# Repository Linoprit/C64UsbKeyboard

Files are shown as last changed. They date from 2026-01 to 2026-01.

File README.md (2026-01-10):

# C64UsbKeyboard
### What it does
Connects old Keyboards from Commodore 64 machines to USB, so you can plug them into Retro [C64Nano](https://github.com/MiSTle-Dev/C64Nano) devices. 

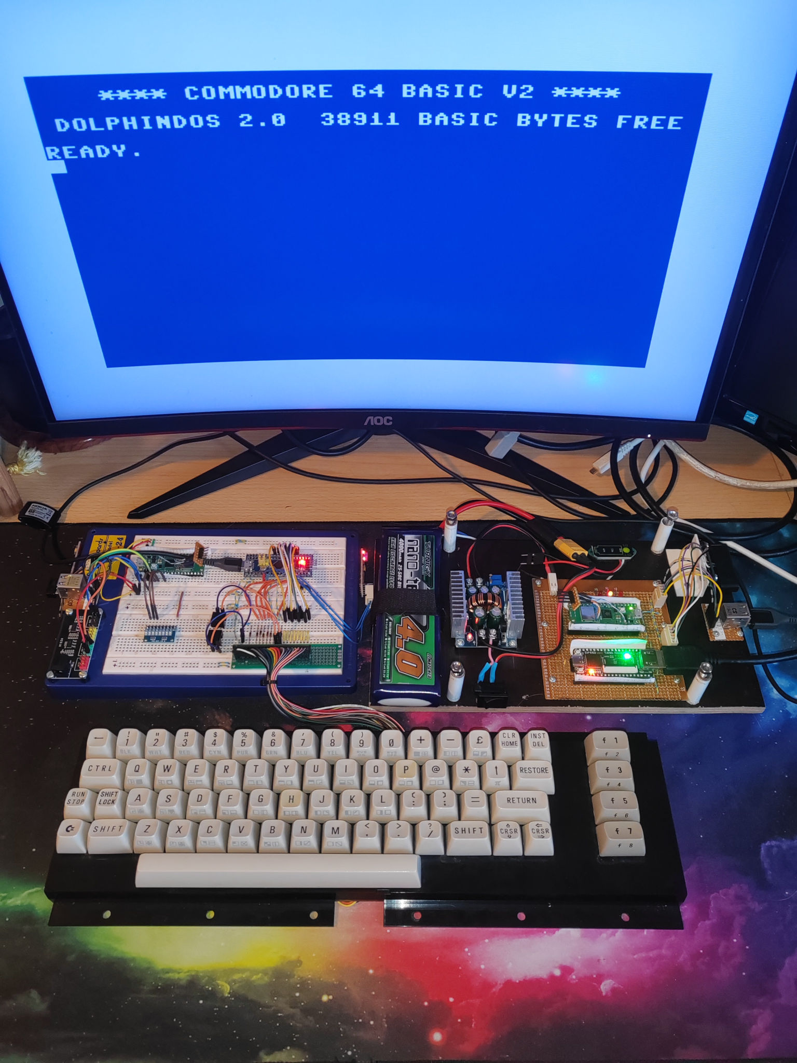
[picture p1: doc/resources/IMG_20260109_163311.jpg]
 

On the left side the breadboard prototype with an aditional RP2040. Right to it my hand soldered C64Nano powered by battery.    

## Why?
Reviving a 40-year-old computer is, well, a questionable idea. But when I heard about Stefan Voss's truly amazing project, I simply had no choice. I had to rebuild it.

Read more about this Retro Computing project here: [C64Nano](https://github.com/MiSTle-Dev/C64Nano?tab=readme-ov-file) and  [MiSTle Develoment](https://github.com/MiSTle-Dev).
Essentially, it's an FPGA and a microcontroller that have been put together to rebuild old computers.

The C64 Nano was working, and I had a great summer playing all the old games I'd played decades ago. But something was missing for a proper retro machine. I remembered buying a broken C64 at a flea market years ago, and that was it! I wanted to take that case and put everything in it. Perfect.

Without question, the original keyboard must work, and that brings us to the point. How do we connect this old keyboard to the C64Nano Companion Board?

To solve this, I thought in many directions, for example extend the Companion Board with a I2C interface, or use the [WeAct RP2350B](https://github.com/WeActStudio/WeActStudio.RP2350BCoreBoard/tree/main) board as Companion, which has plenty of IOs. 

The solution implemented here, simply uses a Bluepill board connected to the USB interface of the C64Nano computer. Easy to build, easy to connect and I have plenty of those boards lying around.

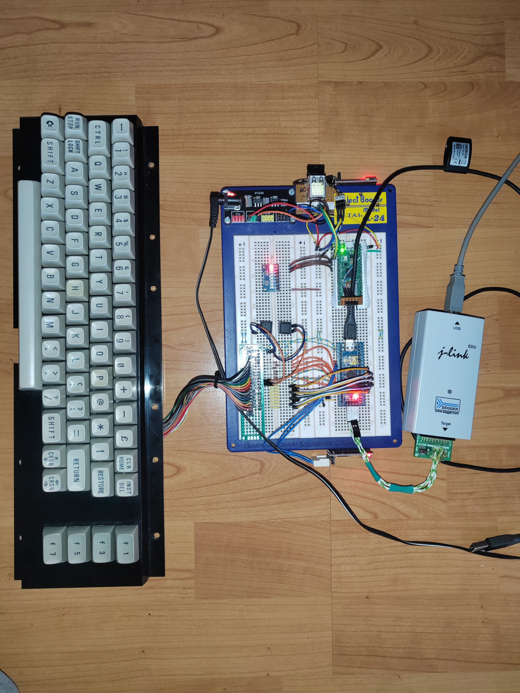
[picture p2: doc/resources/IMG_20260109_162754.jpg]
 

The breadboard with keyboard and programmer. 

After a short search, I found Bob Grant's article in which he described exactly what I wanted to do: [Use a Real Commodore 64 as a USB Keyboard for the VICE emulator](https://bytesnbits.co.uk/commodore-64-usb-keyboard/). He even published his code: [ArduinoKeyboard_C64.ino](https://github.com/getis/c64-usb-keyboard).

Bob uses the Arduino keyboard library, which, however, takes into account the country-specific keyboard layout.
I wanted a mapping of the keyboard matrix to HID codes. This approach is more transparent and easier to debug.

## How to
Well, have a look into the doc folder, there is the schematic. Solder a prototype board, build your own PCB, do what you want :-)

The Bluepill board I used is a Stm32F103C8T6, programmed with a JLink Edu device. 
If you don't want to build the code, simply flash the [release binaries](https://github.com/Linoprit/C64UsbKeyboard/releases). Use a [ST-Link](https://www.google.com/search?q=st+link) device, if you don't own a Segger JLink.

To build the project, you need to install [PlatformIo](https://platformio.org/). The project settings are in platformio.ini.

In the doc folder are some other documents I found usefull. Use them as reference.

## The code
Overall, I used Bob's software and the Arduino Keyboard Library source code.

One small problem arose with the cursor movement of the companion board's OSD. It doesn't accept Shift + Arrow-Up. Therefore, there's a block in the code that intercepts this key combination and sends the correct HID code for Arrow-Up.

Another question was, what to do with the F12 and the play tape keys. Fortunately Bob added the Restore key to the matrix with an addtional row and column. So I simply added two buttons into the matrix and mapped them to corresponding functions.

Oddly enough, I was able to do without key debouncing. If problems arise unexpectedly, it can easily be added later.

> Unplug the Bluepill from USB, before flashing. Otherwise, there is a good chance your host's USB-Driver will get crashed and you need to reboot. The Stm32f103 has no automatic disconnect circuit.

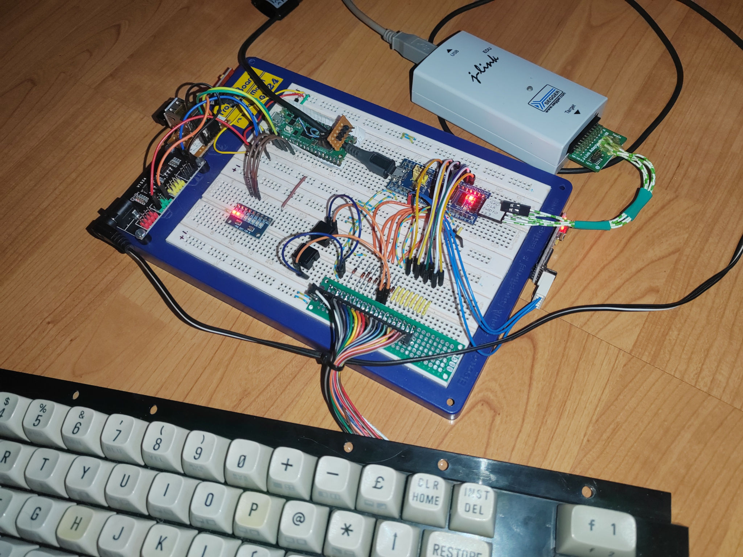
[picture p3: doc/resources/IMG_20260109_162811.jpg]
 

Hope this project is useful to someone.

Have fun.

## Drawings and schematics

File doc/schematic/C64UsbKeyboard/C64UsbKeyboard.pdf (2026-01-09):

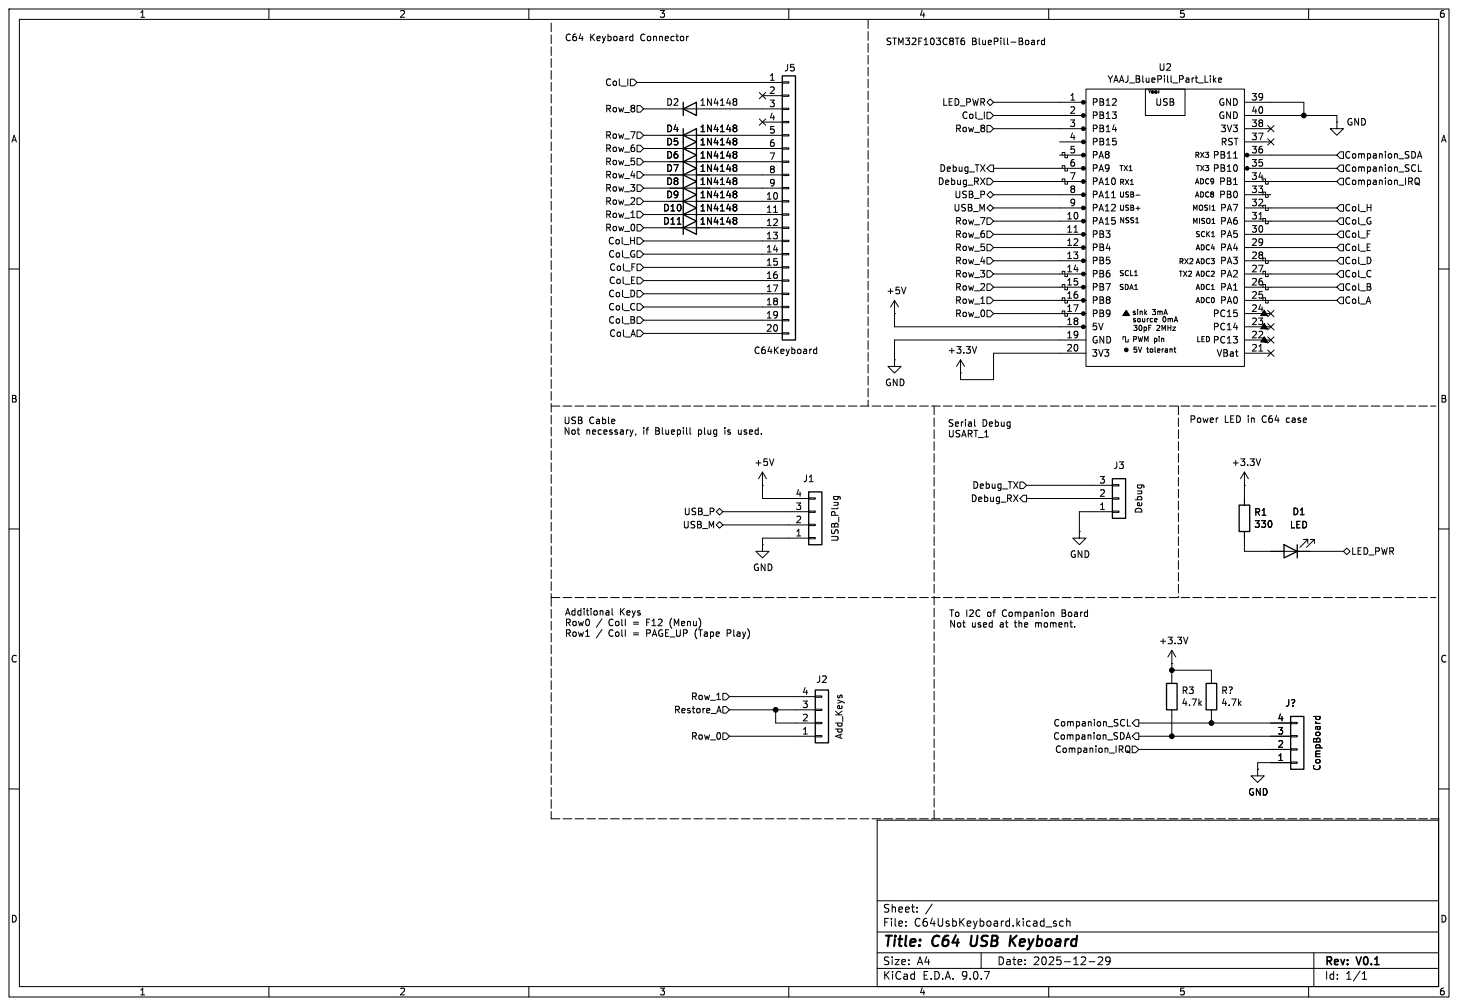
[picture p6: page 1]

Y@@J 30pF 2MHz 5V tolerant source 0mA USB
TX1 RX1 SCL1 SDA1 NSS1 USB- USB+PWM pin

Id: 1/1 Title: C64 USB Keyboard

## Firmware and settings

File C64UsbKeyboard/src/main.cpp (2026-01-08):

// Refer to
// https://bytesnbits.co.uk/commodore-64-usb-keyboard/
// https://github.com/getis/c64-usb-keyboard

#include "MatrixDriver.h"
#include "RawKey.h"
#include "appConfig.h"
#include "stm32f103Config.h"
#include <Arduino.h>
#include "KeysToHid.h"


// ToDo:
// 8 / 8 = Restore = HID KEY_F11
// Missing: Menu = HID KEY_F12
// Missing: TapePlay = HID KEY_PAGEUP
// Modifier Keys (row/col):
// L-Shift (3/1),
// R-Shift (4/6),
// C= (5/0),
//


RowPinsArray rowPins = {row0, row1, row2, row3, row4, row5, row6, row7, row8};
ColPinsArray colPins = {columnA, columnB, columnC, columnD, columnE,
                        columnF, columnG, columnH, columnI};

MatrixDriver matrix = MatrixDriver(rowPins, colPins);
KeysToHid keysToHid;

void setup() {
  Serial.begin(SERIAL_BAUDRATE);
  USB_Begin();
  
  for (uint8_t colPin : colPins) {
    pinMode(colPin, INPUT_PULLUP);
  }

  // init rows as output and set high - inactive
  for (uint8_t rowPin : rowPins) {
    pinMode(rowPin, OUTPUT);
    digitalWrite(rowPin, HIGH);
  }

  Serial.println("finished setup");
  delay(10);
}

void loop() {

  matrix.cycle();

  if (matrix.hasChanged) {
    keysToHid.reportKeys(matrix.actKeys, matrix.scannedKeys);

    for (uint_fast8_t i = 0; i < matrix.scannedKeys; i++) {
      Serial.printf("row: %i / col: %i\n", matrix.actKeys[i].row,
                    matrix.actKeys[i].col);
    }
    if (matrix.scannedKeys == 0) {
      Serial.println("Released");
    }

    keysToHid.dumpKeyReport();
  }

  delay(1);
}

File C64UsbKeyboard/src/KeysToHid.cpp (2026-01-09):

/*
  This is a derivative of Arduinos Keyboard.h, originally by Peter Barrett
*/

#include "C64ToHidKeyMap.h"
#include "KeysToHid.h"
#include <string>

#if defined(_USING_HID)

const uint8_t _hidReportDescriptor[] PROGMEM = {

    //  Keyboard
    0x05, 0x01, // USAGE_PAGE (Generic Desktop)  // 47
    0x09, 0x06, // USAGE (Keyboard)
    0xa1, 0x01, // COLLECTION (Application)
    0x85, 0x02, //   REPORT_ID (2)
    0x05, 0x07, //   USAGE_PAGE (Keyboard)

    0x19, 0xe0, //   USAGE_MINIMUM (Keyboard LeftControl)
    0x29, 0xe7, //   USAGE_MAXIMUM (Keyboard Right GUI)
    0x15, 0x00, //   LOGICAL_MINIMUM (0)
    0x25, 0x01, //   LOGICAL_MAXIMUM (1)
    0x75, 0x01, //   REPORT_SIZE (1)

    0x95, 0x08, //   REPORT_COUNT (8)
    0x81, 0x02, //   INPUT (Data,Var,Abs)
    0x95, 0x01, //   REPORT_COUNT (1)
    0x75, 0x08, //   REPORT_SIZE (8)
    0x81, 0x03, //   INPUT (Cnst,Var,Abs)

    0x95, 0x06, //   REPORT_COUNT (6)
    0x75, 0x08, //   REPORT_SIZE (8)
    0x15, 0x00, //   LOGICAL_MINIMUM (0)
    0x25, 0x73, //   LOGICAL_MAXIMUM (115)
    0x05, 0x07, //   USAGE_PAGE (Keyboard)

    0x19, 0x00, //   USAGE_MINIMUM (Reserved (no event indicated))
    0x29, 0x73, //   USAGE_MAXIMUM (Keyboard Application)
    0x81, 0x00, //   INPUT (Data,Ary,Abs)
    0xc0,       // END_COLLECTION
};

KeysToHid::KeysToHid(void) {
  static HIDSubDescriptor node(_hidReportDescriptor,
                               sizeof(_hidReportDescriptor));
  HID().AppendDescriptor(&node);
}

void KeysToHid::sendReport(KeyReport *keys) {
  HID().SendReport(2, keys, sizeof(KeyReport));
}

void KeysToHid::reportKeys(RawKeysArray rawKeys, uint8_t scannedKeys) {
  HidKeysArray hidKeys;

  releaseAll();

  if (scannedKeys != 0) {
    for (uint_fast8_t i = 0; i < scannedKeys; i++) {
      RawKey rawKey = rawKeys[i];
      hidKeys[i] = rawToHid(rawKey);
    }

    if (shiftAndCursorActive(hidKeys, scannedKeys)) {
      writeCursorToReport(hidKeys, scannedKeys);
    } else {
      writeHidToReport(hidKeys, scannedKeys);
    }
  }

  sendReport(&_keyReport);
}

// Unfortunately the FPGA Companion OSD does not recognize Shift-Cursor keys. 
// So, if we detect Shift and Cursor down or right, we sent the corresponding
// HID-Key and ignore all other keys. 
void KeysToHid::writeCursorToReport(HidKeysArray hidKeys, uint8_t scannedKeys) {
  uint_fast8_t keySlot = 0;
  for (uint_fast8_t i = 0; i < scannedKeys; i++) {
    uint8_t hidCode = hidKeys[i];

    if (hidCode == KEY_RIGHT) {
      _keyReport.keys[keySlot++] = KEY_LEFT; 
    }
    if (hidCode == KEY_DOWN) {
      _keyReport.keys[keySlot++] = KEY_UP; 
    }
    if (keySlot > 5) { 
      break;
    }
  }
}

bool KeysToHid::shiftAndCursorActive(HidKeysArray hidKeys,
                                     uint8_t scannedKeys) {
  bool shiftFlag = false;
  bool cursorFlag = false;

  for (uint_fast8_t i = 0; i < scannedKeys; i++) {
    uint8_t hidCode = hidKeys[i];
    if ((hidCode == KEY_RIGHTSHIFT) || (hidCode == KEY_LEFTSHIFT)) {
      shiftFlag = true;
    }
    if ((hidCode == KEY_RIGHT) || (hidCode == KEY_DOWN)) {
      cursorFlag = true;
    }
    if (shiftFlag && cursorFlag) {
      return true;
    }
  }
  return false;
}

void KeysToHid::writeHidToReport(HidKeysArray hidKeys, uint8_t scannedKeys) {
  uint_fast8_t keySlot = 0;
  for (uint_fast8_t i = 0; i < scannedKeys; i++) {
    if (addIfModifier(hidKeys[i])) {
      continue;
    } else {
      _keyReport.keys[keySlot++] = hidKeys[i];
      // If we have more than 6 keys, we ignore the rest.
      if (keySlot > 5) {
        break;
      }
    }
  }
}

bool KeysToHid::addIfModifier(uint8_t hidCode) {
  if ((hidCode >= KEY_LEFTCTRL) && (hidCode <= KEY_RIGHTMETA)) {
    uint8_t maskedHid = (hidCode & 0x0f);
    uint8_t modifierCode = 1u << maskedHid;
    _keyReport.modifiers |= modifierCode;
    return true;
  }
  return false;
}

uint8_t KeysToHid::rawToHid(RawKey rawKey) {
  if (rawKey.isNone()) {
    return KEY_NONE;
  }
  return C64Keymap[rawKey.col][rawKey.row];
}

void KeysToHid::releaseAll(void) {
  _keyReport.keys[0] = 0;
  _keyReport.keys[1] = 0;
  _keyReport.keys[2] = 0;
  _keyReport.keys[3] = 0;
  _keyReport.keys[4] = 0;
  _keyReport.keys[5] = 0;
  _keyReport.modifiers = 0;
}

void KeysToHid::dumpKeyReport() {

  Serial.printf("Modifiers: %i ", _keyReport.modifiers);
  Serial.printf("Keys: ");
  for (uint_fast8_t i = 0; i < 6; i++) {
    Serial.printf("%i: 0x%x, ", i, _keyReport.keys[i]);
  }
  Serial.println();
}

#endif

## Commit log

2026-01-08 Switched to Platformio
    [C64UsbKeyboard.kicad_pcb, C64UsbKeyboard.kicad_sch, C64UsbKeyboard.sch]
2026-01-09 First working version.
    [C64UsbKeyboard.kicad_sch]
